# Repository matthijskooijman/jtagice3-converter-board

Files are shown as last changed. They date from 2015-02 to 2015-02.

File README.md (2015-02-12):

Pinoccio JTAG backpack
----------------------
This repository contains the schematic and board files for a converter
board to be mounted on top of the Atmel JTAGICE3 programmer, to allow
using bigger 2.54mm connector flatcables whenever possible and
reduce the chance of breaking the fragile 1.27mm connector flatcable.

This project is created using Kicad. The board design was intended as a
single-layer design, with the back layer emulated using wire bridges (so
the vias have a big drill size - be sure to double-check that if you
produce this as a proper double-layer design). There's also some other
caveats, for those and more background, see [this
blogpost](http://www.stderr.nl/Blog/Hardware/Electronics/JTAGICE3ConverterBoard.html).

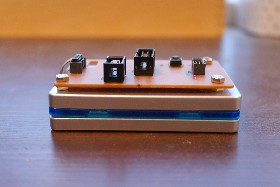
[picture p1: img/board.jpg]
Finished board


License
-------
All content in this repository is licensed under the ["Beluki"
license][1]:

Permission is hereby granted, free of charge, to anyone obtaining a copy
of this document and accompanying files, to do whatever they want with
them without any restriction, including, but not limited to, copying,
modification and redistribution.

NO WARRANTY OF ANY KIND IS PROVIDED.

[1]: https://github.com/Beluki/License/blob/master/Documentation/License

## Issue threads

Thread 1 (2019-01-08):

Improvements for rev2

matthijskooijman, 2019-01-08:
I'm currently building a rev2 of this board and will document some of my rationale here.

The rev1 board I milled served me well, but some of the copper is starting to lift off the board, so time for a new revision, which I intend to professionally mill. I'll probably see if there is an interest to sell them, too.

I found some similar boards, useful to take inspiration from:
 - https://atoomnet.net/atmel-ice-header-adapter/
 - https://m.nl.aliexpress.com/item/32826876052.html
 - https://www.openhardware.io/view/192/Jtag-ICE3-breakout

Some things I want to improve and other thoughts:
 - On rev1, I routed tracks between the pins of the 1.27mm pitch connectors. This gives a very clean layout, but strained the process to the limits. To allow this, I made a custom connector footprint with very narrow pads. On the new board, I want to use a regular footprint. This has 40-mil pads, with 50-mil pitch, so that would leave 10 mil for 1 trace and 2 clearances (so 3.3mil for each). Looking at Seeed, they allow 6 mil by default, and down to 4 mil for extra charge, which is still not enough (though shrinking the pad by 2 mil should be possible). Still, since I want to keep things cheap, I'll likely use 6 mil traces and use a somewhat more complicated layout.
 - I want to add an USB plug and barrel jack (possible others) for power input, which can then be supplied to the target board (either directly or through a regulator, possibly multiple). Power source can be chosen (or disabled) with jumpers. All inspired by https://www.openhardware.io/view/192/Jtag-ICE3-breakout
 - Support the Atmel ICE in addition to the JTAGICE3. These are very similar boards. The ICE has connectors for AVR and SAM, but as [this post](https://atoomnet.net/atmel-ice-header-adapter/) confirms, these are just the same pins in different pinouts (so we can just connect to either one, and convert to the other on the converter board). Also, it seems that the JTAGICE3 with the latest firmware uses the same EDBG protocol as the ICE and should also support SAM targets.

Connectors to use
------------------------
One important decision is what connectors to put on the board (both in terms of pinout and pitch). Here's what I've been considering now:
 - The 6-pin AVR-ISP connector. This is the most commonly used ISP connector, so should definitely be present. AFAIK it is almost always 2.54mm. Tag-connect uses another pitch on the target side, but I think the cable uses 2.54mm on the programmer side as well.
 - The 10-pin AVR-ISP connector. ...
